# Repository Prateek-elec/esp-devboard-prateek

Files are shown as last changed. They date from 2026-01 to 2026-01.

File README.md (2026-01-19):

# ESP32-C3 Dev Board (KiCad) ⚡

A custom **ESP32-C3 development board** designed in **KiCad**, built for compact embedded prototyping with
**USB-C input, LiPo charging, stable 3.3V regulation**, and expansion headers for sensors/modules.

✅ Focus: **Embedded Hardware • PCB Design • Power + IO Integration**

---

## ✅ Key Features
- **ESP32-C3-WROOM module**
- **USB-C power input**
- **Single-cell LiPo charging circuit**
- **3.3V regulation** for stable MCU + peripherals
- **Boot / Reset circuit** for easy programming
- **GPIO breakout headers** for expansion
- Sensor/module support (example: **BME280**, mic amplifier, photo sensor)

---

## 📷 PCB Preview
### Top Layer
Top

### Bottom Layer
Bottom

---

## 📂 Repository Structure
```txt
esp-devboard-prateek/
│── README.md
│── LICENSE
│
├── hardware/
│   └── kicad/               # KiCad project files (.kicad_pro/.sch/.pcb)
│
├── docs/
│   ├── schematic.pdf        # Schematic export
│   └── pcb-renders/         # Top/Bottom/3D screenshots
│
└── fabrication/             # (optional) Gerbers, drill, BOM, PnP outputs

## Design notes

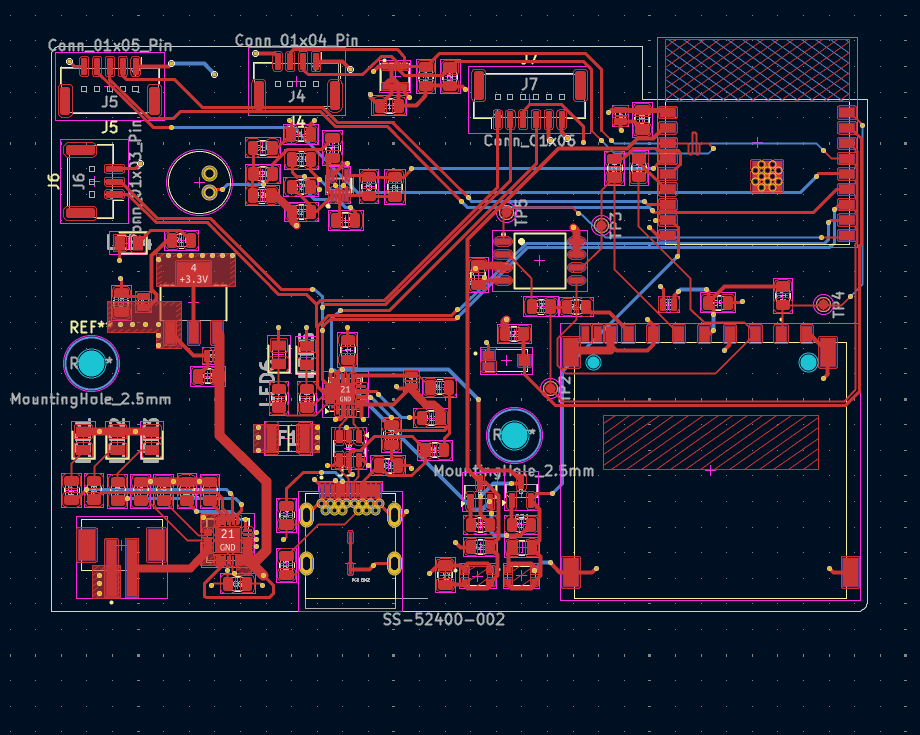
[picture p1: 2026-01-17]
docs/Screenshot 2026-01-17 211116.png

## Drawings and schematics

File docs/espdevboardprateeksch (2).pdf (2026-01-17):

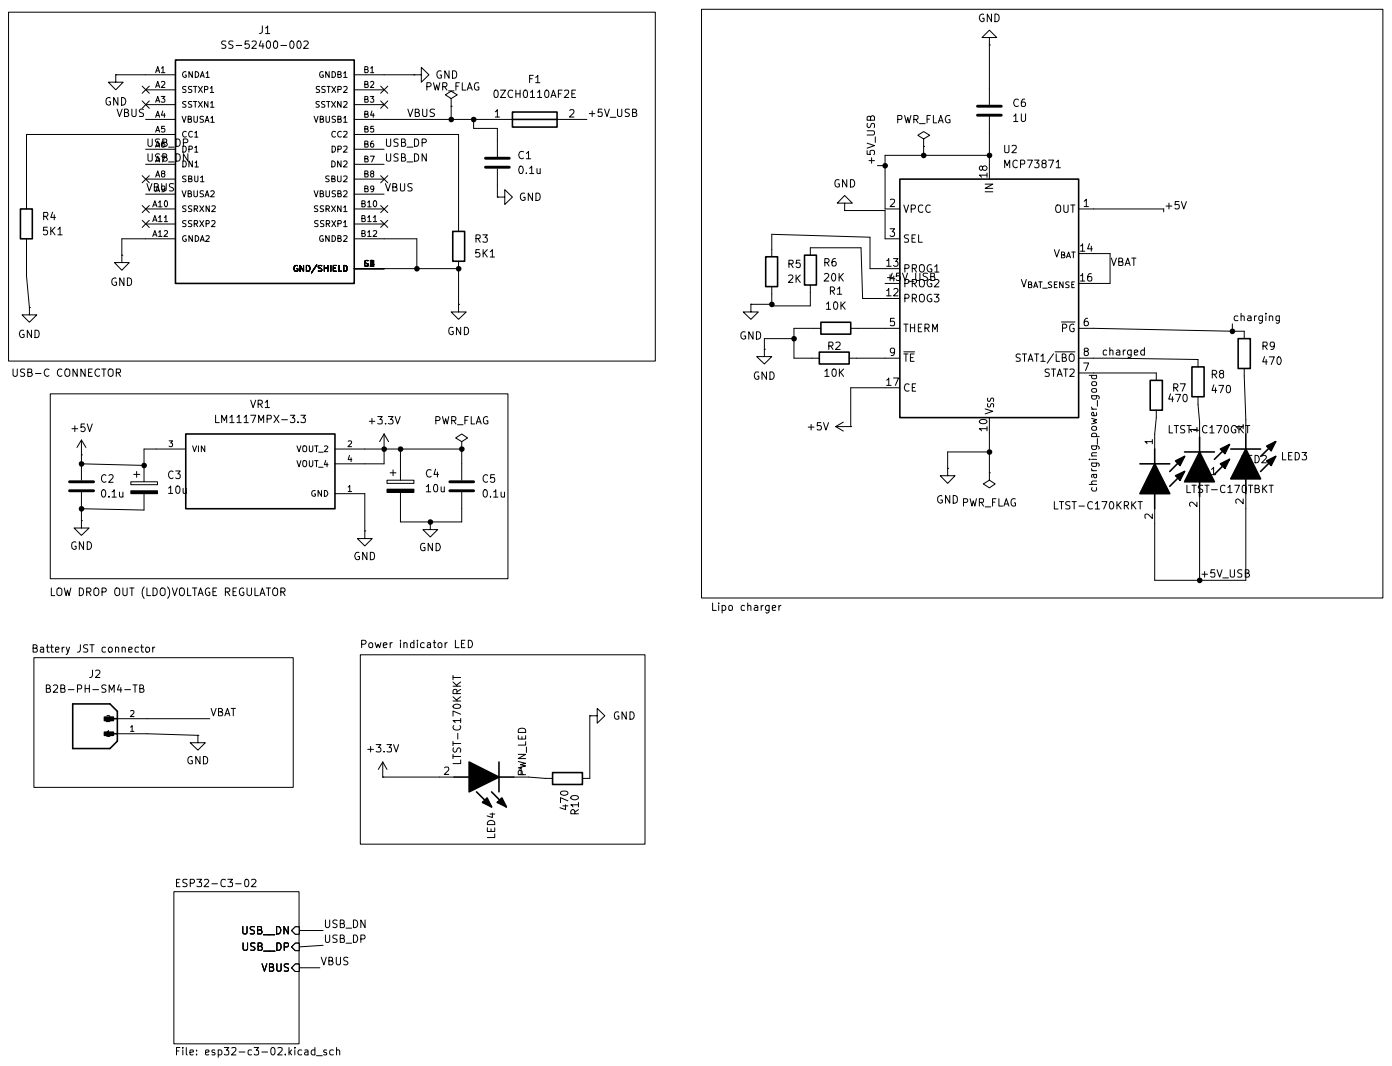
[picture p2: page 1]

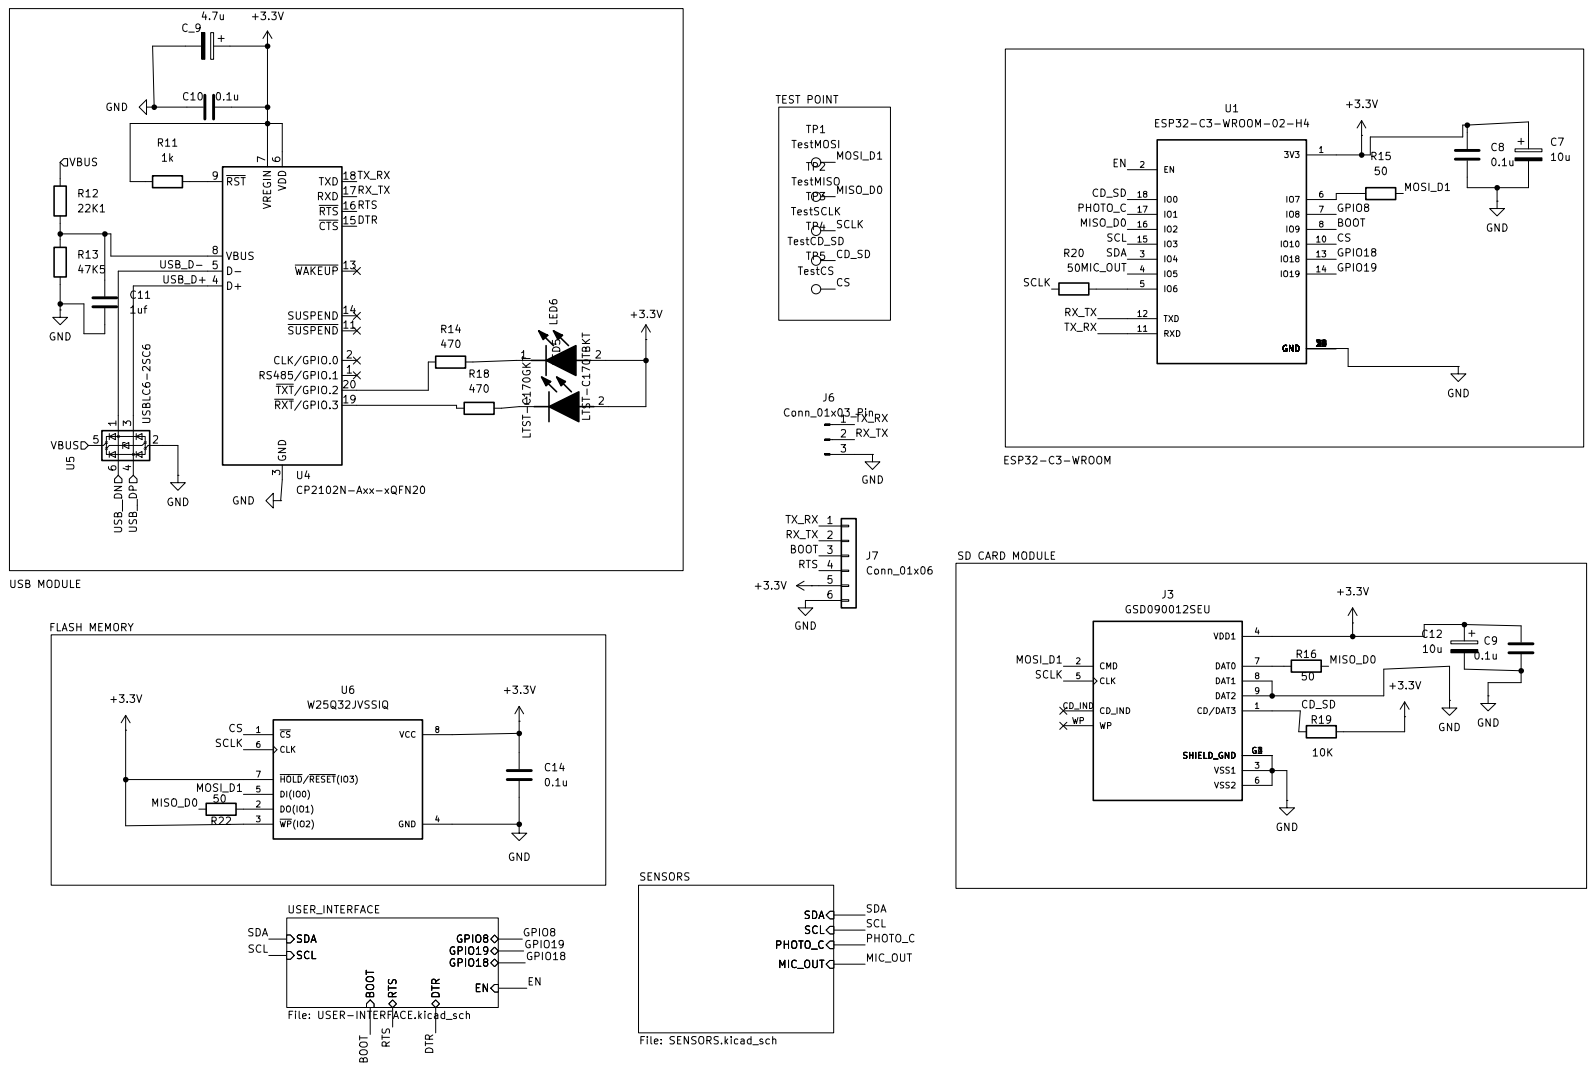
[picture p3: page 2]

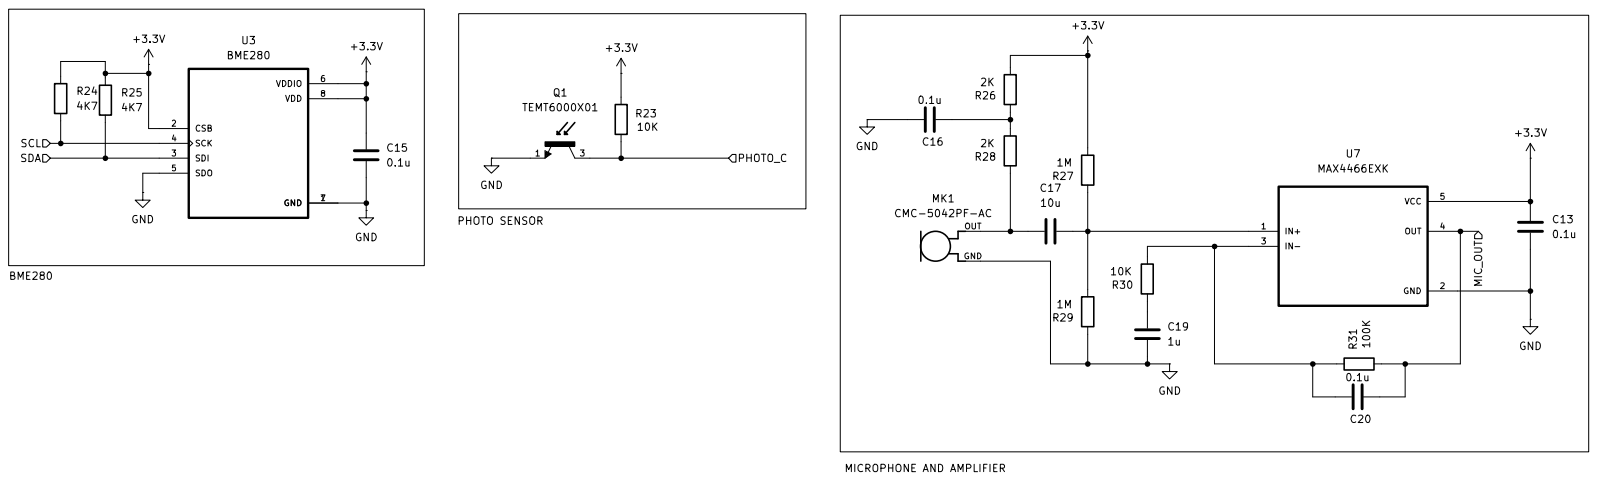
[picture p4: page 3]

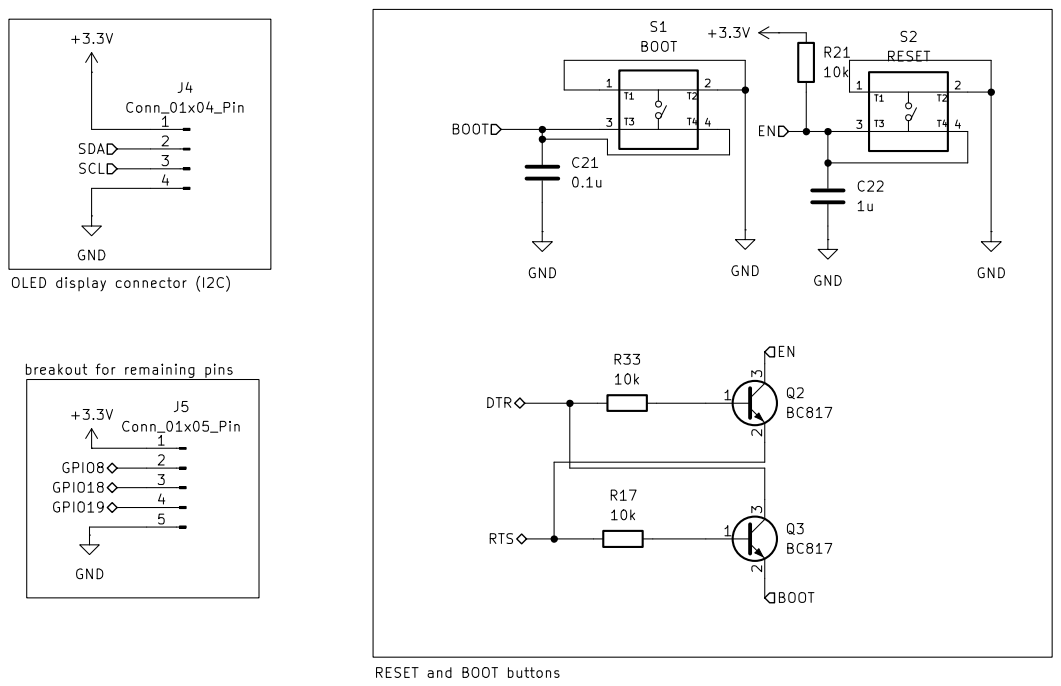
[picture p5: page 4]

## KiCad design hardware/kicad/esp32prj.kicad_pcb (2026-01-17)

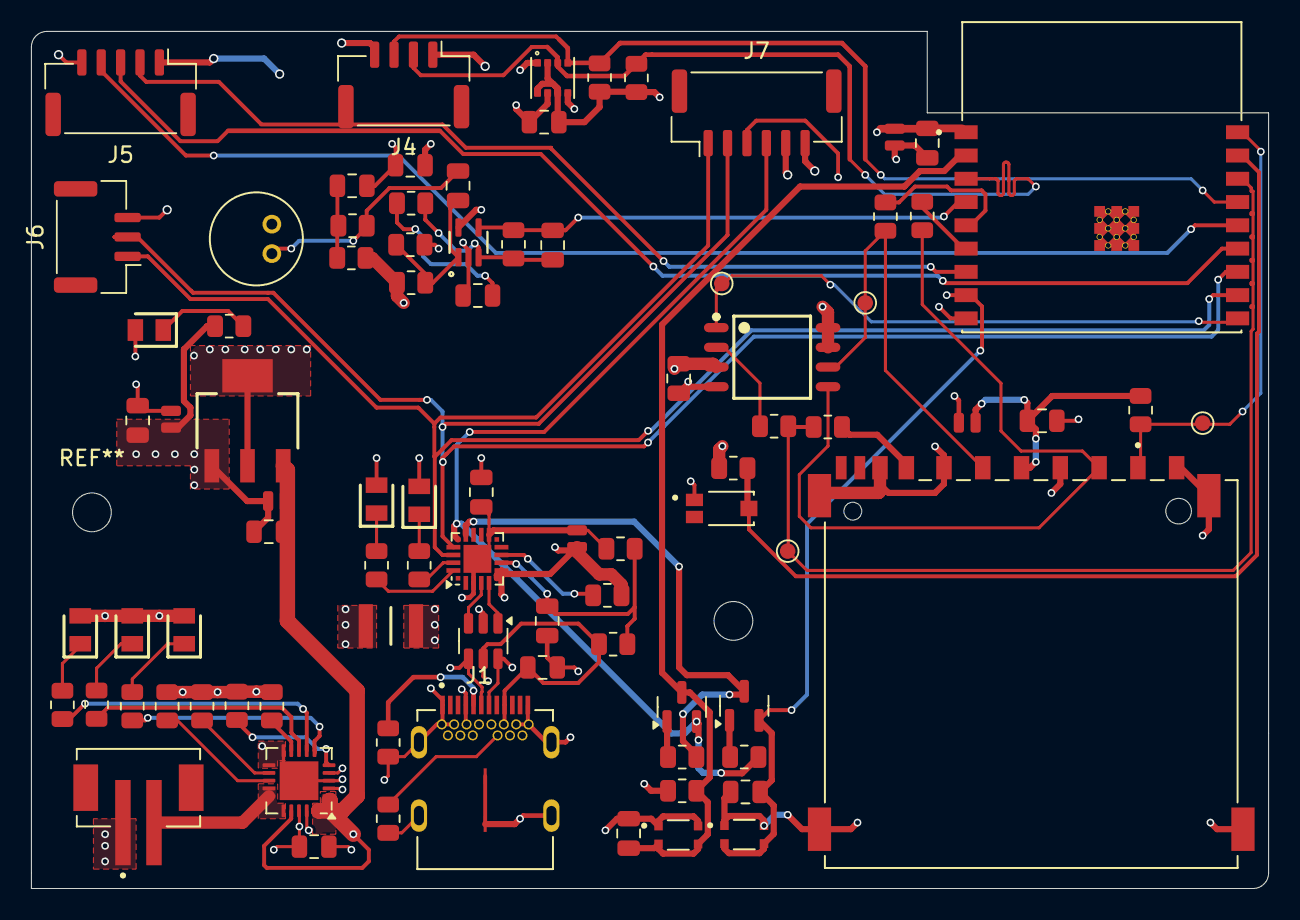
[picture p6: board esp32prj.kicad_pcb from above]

Board: 4 copper layers, 79.8 x 55.2 mm, 86 parts (0 on the bottom side), 58 nets.

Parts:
C1, C2, C5, C8, C9, C10, C13, C14, C15, C16, C20, C21: 0.1u; C_0805_2012Metric
C3, C4, C7, C12: 10u; C_0504_1310Metric
C6: 1U; C_0805_2012Metric
C11: 1uf; C_0805_2012Metric
C17: 10u; C_0805_2012Metric
C19, C22: 1u; C_0805_2012Metric
C_9: 4.7u; C_0504_1310Metric
F1: 0ZCH0110AF2E; FUSC3226X100N
J1: SS-52400-002; BELFUSE_SS-52400-002
J2: B2B-PH-SM4-TB; JST_B2B-PH-SM4-TB
J3: GSD090012SEU; AMPHENOL_GSD090012SEU
J4: Conn_01x04_Pin; JST_GH_BM04B-GHS-TBT_1x04-1MP_P1.25mm_Vertical
J5: Conn_01x05_Pin; JST_GH_BM05B-GHS-TBT_1x05-1MP_P1.25mm_Vertical
J6: Conn_01x03_Pin; JST_GH_BM03B-GHS-TBT_1x03-1MP_P1.25mm_Vertical
J7: Conn_01x06; JST_GH_BM06B-GHS-TBT_1x06-1MP_P1.25mm_Vertical
LED1, LED4: LTST-C170KRKT; LEDC2012X120N
LED2, LED5: LTST-C170GKT; LEDC2012X120N
LED3, LED6: LTST-C170TBKT; LEDC2012X120N
MK1: CMC-5042PF-AC; CUI_CMC-5042PF-AC
Q1: TEMT6000X01; TRANS_TEMT6000X01
Q2, Q3: BC817; SOT-23
R1, R2, R19, R23, R30: 10K; R_0805_2012Metric
R3, R4: 5K1; R_0805_2012Metric
R5, R26, R28: 2K; R_0805_2012Metric
R6: 20K; R_0805_2012Metric
R7, R8, R9, R10, R14, R18: 470; R_0805_2012Metric
R11: 1k; R_0805_2012Metric
R12: 22K1; R_0805_2012Metric
R13: 47K5; R_0805_2012Metric
R15, R16, R20, R22: 50; R_0805_2012Metric
R17, R21, R33: 10k; R_0805_2012Metric
R24, R25: 4K7; R_0805_2012Metric
R27, R29: 1M; R_0805_2012Metric
R31: 100K; R_0805_2012Metric
S1: BOOT; SW_USLPT2819DT2TR
S2: RESET; SW_USLPT2819DT2TR
TP2: TestMISO; TestPoint_Pad_D1.0mm
TP3: TestSCLK; TestPoint_Pad_D1.0mm
TP4: TestCD_SD; TestPoint_Pad_D1.0mm
TP5: TestCS; TestPoint_Pad_D1.0mm
U1: ESP32-C3-WROOM-02-H4; MODULE_ESP32-C3-WROOM-02-H4
U2: MCP73871; QFN-20-1EP_4x4mm_P0.5mm_EP2.5x2.5mm
U3: BME280; PSON65P250X250X100-8N
U4: CP2102N-Axx-xQFN20; SiliconLabs_QFN-20-1EP_3x3mm_P0.5mm_EP1.8x1.8mm
U5: USBLC6-2SC6; SOT-23-6
U6: W25Q32JVSSIQ; SOIC127P790X216-8N
U7: MAX4466EXK; SOT65P210X110-5N
VR1: LM1117MPX-3.3; VREG_LM1117MPX-3.3

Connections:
+3.3V: C4.1, C5.1, C7.1, C8.1, C9.1, C10.2, C12.1, C13.1, C14.1, C15.1, C_9.1, J3.4 (VDD1), J4.1, J5.1, J7.5, LED4.2 (A), LED5.2 (A), LED6.2 (A), R11.1, R19.2, R21.2, R23.1, R24.1, R25.1, R26.2, R27.2, U1.1 (3V3), U3.2 (CSB), U3.6 (VDDIO), U3.8 (VDD), U4.6 (VDD), U4.7 (VREGIN), U6.3 (~WP(IO2)), U6.7 (~HOLD/~RESET(IO3)), U6.8 (VCC), U7.5 (VCC), VR1.2 (VOUT_2), VR1.4 (VOUT_4)
+5V: C2.1, C3.1, U2.1 (OUT), U2.17 (CE), U2.20 (OUT), VR1.3 (VIN)
/+5V_USB: C6.2, F1.2, LED1.2 (A), LED2.2 (A), LED3.2 (A), U2.2 (VPCC), U2.4 (PROG2), U2.18 (IN), U2.19 (IN)
/ESP32-C3-02/BOOT: C21.1, J7.3, Q3.2 (E), S1.3, S1.4, U1.8 (IO9)
/ESP32-C3-02/CD_SD: J3.1 (CD/DAT3), R19.1, TP4.1, U1.18 (IO0)
/ESP32-C3-02/CS: TP5.1, U1.10 (IO10), U6.1 (~CS)
/ESP32-C3-02/DTR: Q3.3 (C), R33.1, U4.15 (~CTS)
/ESP32-C3-02/EN: C22.1, Q2.3 (C), R21.1, S2.3, S2.4, U1.2 (EN)
/ESP32-C3-02/GPIO8: J5.2, U1.7 (IO8)
/ESP32-C3-02/GPIO18: J5.3, U1.13 (IO18)
/ESP32-C3-02/GPIO19: J5.4, U1.14 (IO19)
/ESP32-C3-02/MIC_OUT: C20.2, R31.2, U1.4 (IO5), U7.4 (OUT)
/ESP32-C3-02/MISO_D0: R16.2, R22.2, TP2.1, U1.16 (IO2)
/ESP32-C3-02/MOSI_D1: J3.2 (CMD), R15.2, U6.5 (DI(IO0))
/ESP32-C3-02/PHOTO_C: Q1.3, R23.2, U1.17 (IO1)
/ESP32-C3-02/RTS: J7.4, Q2.2 (E), R17.1, U4.16 (~RTS)
/ESP32-C3-02/RX_TX: J6.2, J7.2, U1.12 (TXD), U4.17 (RXD)
/ESP32-C3-02/SCL: J4.3, R24.2, U1.15 (IO3), U3.4 (SCK)
/ESP32-C3-02/SCLK: J3.5 (CLK), R20.1, TP3.1, U6.6 (CLK)
/ESP32-C3-02/SDA: J4.2, R25.2, U1.3 (IO4), U3.3 (SDI)
/ESP32-C3-02/TX_RX: J6.1, J7.1, U1.11 (RXD), U4.18 (TXD)
/ESP32-C3-02/USB_D+: U4.4 (D+), U5.3 (I/O2)
/ESP32-C3-02/USB_D-: U4.5 (D-), U5.1 (I/O1)
/PWN_LED: LED4.1 (K), R10.2
/USB_DN: J1.A7 (DN1), J1.B7 (DN2), U5.6 (I/O1)
/USB_DP: J1.A6 (DP1), J1.B6 (DP2), U5.4 (I/O2)
/VBAT: J2.2, U2.14 (V_{BAT}), U2.15 (V_{BAT}), U2.16 (V_{BAT_SENSE})
/VBUS: C1.1, F1.1, J1.A4 (VBUSA1), J1.A9 (VBUSA2), J1.B4 (VBUSB1), J1.B9 (VBUSB2), R12.1, U5.5 (VBUS)
/charged: R8.1, U2.8 (STAT1/~LBO)
/charging: R9.1, U2.6 (~PG)
/charging_power_good: R7.1, U2.7 (STAT2)
GND: C1.2, C2.2, C3.2, C4.2, C5.2, C6.1, C7.2, C8.2, C9.2, C10.1, C11.2, C12.2, C13.2, C14.2, C15.2, C16.1, C19.2, C21.2, C22.2, C_9.2, J1.A1 (GNDA1), J1.A12 (GNDA2), J1.B1 (GNDB1), J1.B12 (GNDB2), J1.G1 (GND/SHIELD), J1.G2 (GND/SHIELD), J1.G3 (GND/SHIELD), J1.G4 (GND/SHIELD), J1.S1 (GND/SHIELD), J1.S2 (GND/SHIELD), J1.S3 (GND/SHIELD), J1.S4 (GND/SHIELD), J2.1, J3.3 (VSS1), J3.6 (VSS2), J3.8 (DAT1), J3.9 (DAT2), J3.G1 (SHIELD_GND), J3.G2 (SHIELD_GND), J3.G3 (SHIELD_GND), J3.G4 (SHIELD_GND), J4.4, J5.5, J6.3, J7.6, MK1.GND, Q1.1, R1.1, R2.1, R3.2, R4.2, R5.2, R6.2, R10.1, R13.2, R29.1, S1.1, S1.2, S2.1, S2.2, U1.9 (GND), U1.19 (GND), U1.20 (GND), U1.21 (GND), U1.22 (GND), U1.23 (GND), U1.24 (GND), U1.25 (GND), U1.26 (GND), U1.27 (GND), U1.28 (GND), U1.29 (GND), U1.30 (GND), U1.31 (GND), U1.32 (GND), U1.33 (GND), U1.34 (GND), U1.35 (GND), U1.36 (GND), U1.37 (GND), U1.38 (GND), U1.39 (GND), U2.3 (SEL), U2.10 (V_{SS}), U2.11 (V_{SS}), U2.21 (V_{SS}), U3.1 (GND), U3.5 (SDO), U3.7 (GND), U4.3 (GND), U4.12 (GND), U4.21 (GND), U5.2 (GND), U6.4 (GND), U7.2 (GND), VR1.1 (GND)
unnamed: C16.2, R26.1, R28.2
unnamed: C17.1, MK1.OUT, R28.1
unnamed: C19.1, R30.1
unnamed: J1.A5 (CC1), R4.1
unnamed: J1.B5 (CC2), R3.1
unnamed: J3.7 (DAT0), R16.1
unnamed: LED1.1 (K), R7.2
unnamed: LED2.1 (K), R8.2
unnamed: LED3.1 (K), R9.2
unnamed: LED5.1 (K), R18.2
unnamed: LED6.1 (K), R14.2
unnamed: Q2.1 (B), R33.2
unnamed: Q3.1 (B), R17.2
unnamed: R20.2, U1.5 (IO6)
unnamed: R15.1, U1.6 (IO7)
unnamed: R5.1, U2.13 (PROG1)
unnamed: R6.1, U2.12 (PROG3)
unnamed: R1.2, U2.5 (THERM)
unnamed: R2.2, U2.9 (~TE)
unnamed: C11.1, R12.2, R13.1, U4.8 (VBUS)
unnamed: R11.2, U4.9 (~RST)
unnamed: R18.1, U4.19 (~RXT/GPIO.3)
unnamed: R14.1, U4.20 (~TXT/GPIO.2)
unnamed: R22.1, U6.2 (DO(IO1))
unnamed: C17.2, R27.1, R29.2, U7.1 (IN+)
unnamed: C20.1, R30.2, R31.1, U7.3 (IN-)
